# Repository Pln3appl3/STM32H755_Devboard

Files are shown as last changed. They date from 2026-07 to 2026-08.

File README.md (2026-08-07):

# STM32H755_Devboard
A custom devboard using the STM32H755 chip that I built to be used to prototype and test complex robotics machines I plan to build in the future and consists of MicroSD card slot, CAN-FD inbuilt, USB-C, SWD Debug header, boot and reset buttons to flash with USB-C, and external flash.

## Why did I make this?
I made this as I wanted a high-end microcontroller that has a dual core processor and has multiple functionalities, and that eventually led to me making this custom devboard that I plan on using to test prototypes for any complex robots I want to make and not worry about being bottlenecked by the microcontroller.

## Pictures
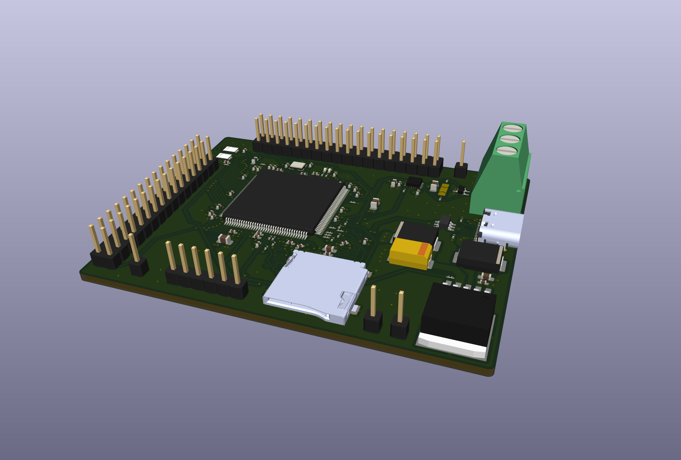
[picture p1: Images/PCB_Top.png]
PCB Top

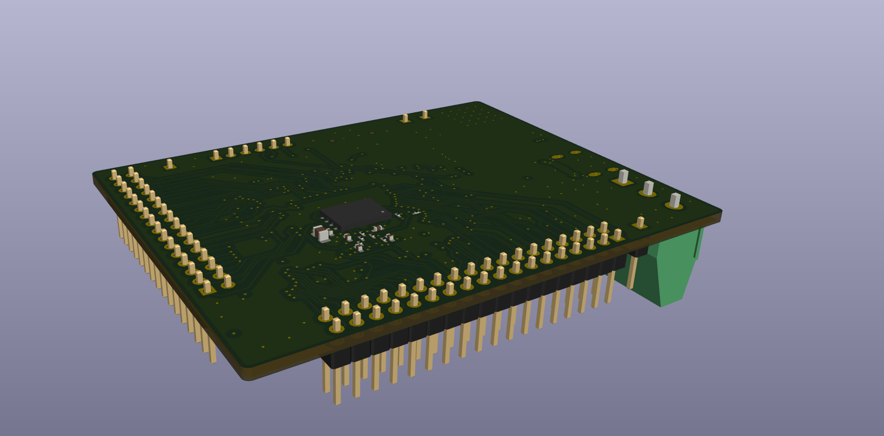
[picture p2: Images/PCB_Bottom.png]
PCB Bottom


## Footprint Pictures
### Top Layer
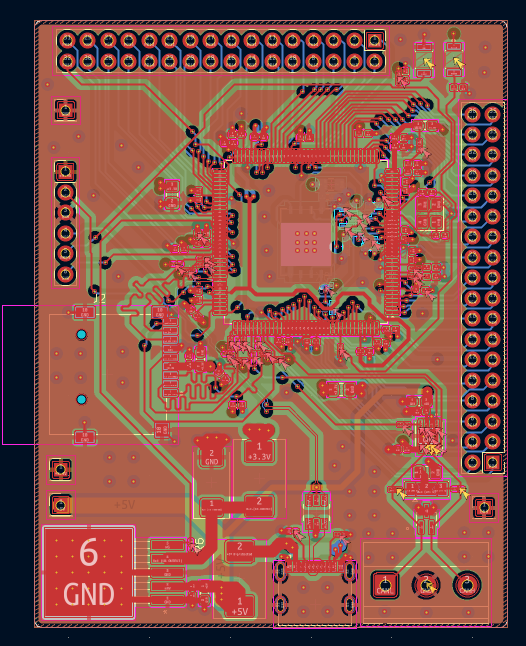
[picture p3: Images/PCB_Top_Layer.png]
PCB Top Layer


### GND Layer
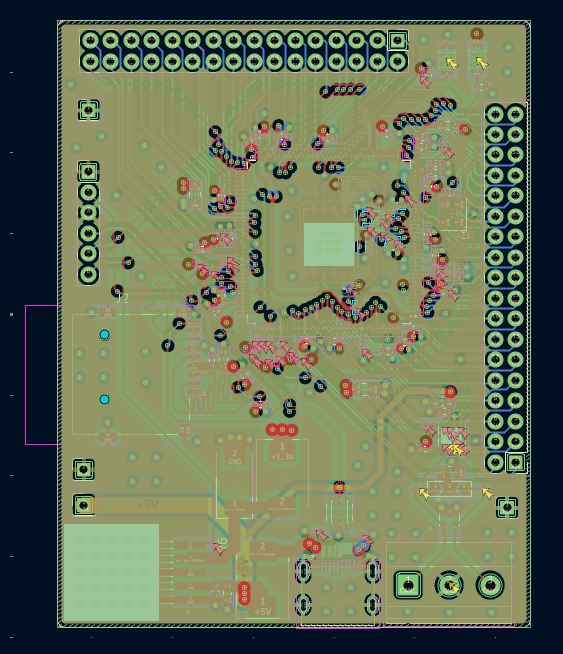
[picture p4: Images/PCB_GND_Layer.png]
PCB GND Layer


### Power Layer
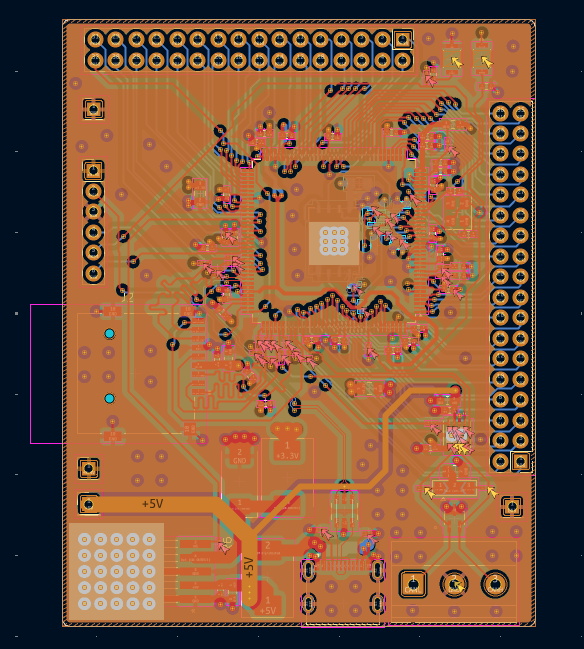
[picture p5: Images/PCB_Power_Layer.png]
PCB Power Layer


### Bottom Layer
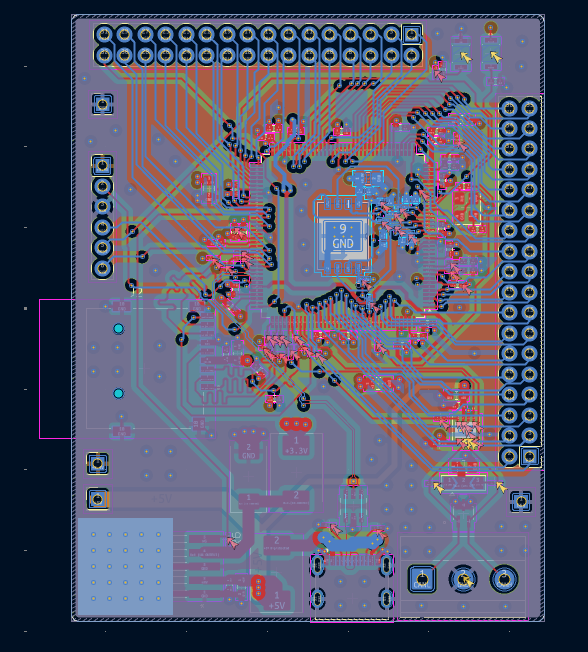
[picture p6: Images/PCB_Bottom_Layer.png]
PCB Bottom Layer


### BOM
| Component | Amount | Price per unit | Total Price | Purpose | Link |
|---|---|---|---|---|---|
| STM32H755ZIT3 | 1 | $20.11 | $20.11 | MCU for the board | https://www.digikey.com/en/products/detail/stmicroelectronics/STM32H755ZIT3/18086228 |
| TYPE-C-16P-3MD | 1 | $0.19 | $1.90 | USB-C data and power (Had to buy 10 as that was the minimum purchase amount | https://www.digikey.com/en/products/detail/shenzhen-shouhan-technology-co-ltd/type-c-16p-3md/29627623 |
| USBLC6-2SC6Y | 1 | $0.67 | $0.67 | ESD protection for data lines | https://www.digikey.com/en/products/detail/stmicroelectronics/usblc6-2sc6y/2819177 |
| SSC54-E3/57T | 2 | $1.05 | $2.10 | Diode to prevent reverse current | https://www.digikey.com/en/products/detail/vishay-general-semiconductor-diodes-division/ssc54-e3-57t/1091564 |
| TPS75733KTTR | 1 | $11.26 | $11.26 | 3.3V LDO | https://www.digikey.com/en/products/detail/texas-instruments/tps75733kttr/1673150 |
| TCAN1044VDRBRQ1 | 1 | $1.86 | $1.86 | CAN-FD Transceiver | https://www.digikey.com/en/products/detail/texas-instruments/tcan1044vdrbrq1/13245687 |
| ESD2CAN24DCKRQ1 | 1 | $0.40 | $0.40 | ESD protection for CAN-FD | https://www.digikey.com/en/products/detail/texas-instruments/esd2can24dckrq1/16982070 |
| TSX-3225_25.0000MF20X-AJ0 | 1 | $0.37 | $0.37 | 25MHz crystal | https://www.digikey.com/en/products/detail/epson/TSX-3225-25-0000MF20X-AJ0/5168442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 |
| W25Q256JVEIQ TR | 1 | $6.08 | $6.08 | External Flash | https://www.digikey.com/en/products/detail/winbond-electronics/w25q256jveiq-tr/5803969 |
| MSD-1-A | 1 | $0.38 | $0.38 | MicroSD card port | https://www.digikey.com/en/products/detail/same-sky-formerly-cui-devices/msd-1-a/21799641 |
| EVP-AWBD4A | 2 | $0.30 | $0.60 | Button for boot and reset | https://www.digikey.com/en/products/detail/panasonic-industry/EVP-AWBD4A/8568273 |
| GRM155Z71A225KE44D | 2 | $0.15 | $0.30 | VCAP Capacitors with under .1 Ohm ESR | https://www.digikey.com/en/products/detail/murata-electronics/GRM155Z71A225KE44D/10264880 |
| C2012X7R1A475K085AC | 4 | $0.27 | $1.08 | Buk and filtering capacitor | https://www.digikey.com/en/products/detail/tdk/C2012X7R1A475K085AC/3951763 |
| GRT188R61C106KE13D | 3 | $0.29 | $0.87 | Bulk Capacitor | https://www.digikey.com/en/products/detail/murata-electronics/GRT188R61C106KE13D/5416739 |
| KAM05CR71A105KH | 4 | $0.17 | $0.68 | Decoupling/Filtering capacitor | https://www.digikey.com/en/products/detail/kyocera-avx/KAM05CR71A105KH/22198421 |
| CC0402JRX7R8BB104 | 31 | $0.05 | $1.58 | Decoupling capacitor | https://www.digikey.com/en/products/detail/yageo/CC0402JRX7R8BB104/11491448 |
| C0402C100F4HACAUTO | 2 | $0.18 | $0.36 | Crystal load capacitor | https://www.digikey.com/en/products/detail/kemet/C0402C100F4HACAUTO/7955039 |
| T495D476K025ATE250 | 1 | $2.36 | $2.36 | LDO output bulk capacitor | https://www.digikey.com/en/products/detail/kemet/T495D476K025ATE250/3760574 |
| BLM18SG121TN1D | 1 | $0.14 | $0.14 | Ferrite bead for analog filtering | https://www.digikey.com/en/products/detail/murata-electronics/blm18sg121tn1d/1016155 |
| RC0201JR-070RL | 1 | $0.10 | $0.10 | Resistor Jumper for VREF+ | https://www.digikey.com/en/products/detail/yageo/RC0201JR-070RL/1948898 |
| RC0201FR-0710KL | 10 | $0.03 | $0.34 | 10K ohm Pull-up resistor | https://www.digikey.com/en/products/detail/yageo/RC0201FR-0710KL/1948870 |
| RC0201FR-0733RL | 2 | $0.10 | $0.20 | 33 Ohm dampening resistor | https://www.digikey.com/en/products/detail/yageo/RC0201FR-0733RL/1948893 |
| RC0201FR-0722RL | 12 | $0.03 | $0.41 | 22 Ohm dampening resistor | https://www.digikey.com/en/products/detail/yageo/RC0201FR-0722RL/5280378 |
| RC0201FR-07330RL | 2 | $0.10 | $0.20 | 330 Ohm current limiting resistor | https://www.digikey.com/en/products/detail/yageo/RC0201FR-07330RL/5280464 |
| RC0201FR-135K1L | 2 | $0.10 | $0.20 | USB-C detection pull-down resistor | https://www.digikey.com/en/products/detail/yageo/RC0201FR-135K1L/17017100 |
| RC0201FR-0760R4L | 2 | $0.10 | $0.20 | CAN-FD Termination resistors | https://www.digikey.com/en/products/detail/yageo/RC0201FR-0760R4L/5280609 |
| XZMDK68W-2 | 1 | $0.23 | $0.23 | Debug LED | https://www.digikey.com/en/products/detail/sunled/XZMDK68W-2/4745956 |
| XZVG68W-2 | 1 | $0.26 | $0.26 | Debug LED | https://www.digikey.com/en/products/detail/sunled/XZVG68W-2/4745975 |
| M50-3530242 | 39 | $0.08 | $3.28 | Headers | https://www.digikey.com/en/products/detail/harwin-inc/M50-3530242/7044013 |
| 1729131 | 1 | $1.44 | $1.44 | CAN-FD Terminal Block | https://www.digikey.com/en/products/detail/phoenix-contact/1729131/260616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 |
|PCB |5 | $15.32 | $76.60 | ||
| Total | | | $130.36 | | |

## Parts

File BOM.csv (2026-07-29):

Name | Price
PCB | $53.76
Parts | $76.60
Total | $130.36

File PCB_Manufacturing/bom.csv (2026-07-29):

Component | Amount | Price per unit | Total Price | Link
STM32H755ZIT3 | 1 | $20.11 | $20.11 | https://www.digikey.com/en/products/detail/stmicroelectronics/STM32H755ZIT3/18086228
TYPE-C-16P-3MD | 1 | $0.19 | $1.90 | https://www.digikey.com/en/products/detail/shenzhen-shouhan-technology-co-ltd/type-c-16p-3md/29627623
USBLC6-2SC6Y | 1 | $0.67 | $0.67 | https://www.digikey.com/en/products/detail/stmicroelectronics/usblc6-2sc6y/2819177
SSC54-E3/57T | 2 | $1.05 | $2.10 | https://www.digikey.com/en/products/detail/vishay-general-semiconductor-diodes-division/ssc54-e3-57t/1091564
TPS75733KTTR | 1 | $11.26 | $11.26 | https://www.digikey.com/en/products/detail/texas-instruments/tps75733kttr/1673150
TCAN1044VDRBRQ1 | 1 | $1.86 | $1.86 | https://www.digikey.com/en/products/detail/texas-instruments/tcan1044vdrbrq1/13245687
ESD2CAN24DCKRQ1 | 1 | $0.40 | $0.40 | https://www.digikey.com/en/products/detail/texas-instruments/esd2can24dckrq1/16982070
TSX-3225_25.0000MF20X-AJ0 | 1 | $0.37 | $0.37 | https://www.digikey.com/en/products/detail/epson/TSX-3225-25-0000MF20X-AJ0/5168442
W25Q256JVEIQ TR | 1 | $6.08 | $6.08 | https://www.digikey.com/en/products/detail/winbond-electronics/w25q256jveiq-tr/5803969
MSD-1-A | 1 | $0.38 | $0.38 | https://www.digikey.com/en/products/detail/same-sky-formerly-cui-devices/msd-1-a/21799641
EVP-AWBD4A | 2 | $0.30 | $0.60 | https://www.digikey.com/en/products/detail/panasonic-industry/EVP-AWBD4A/8568273
GRM155Z71A225KE44D | 2 | $0.15 | $0.30 | https://www.digikey.com/en/products/detail/murata-electronics/GRM155Z71A225KE44D/10264880
C2012X7R1A475K085AC | 4 | $0.27 | $1.08 | https://www.digikey.com/en/products/detail/tdk/C2012X7R1A475K085AC/3951763
GRT188R61C106KE13D | 3 | $0.29 | $0.87 | https://www.digikey.com/en/products/detail/murata-electronics/GRT188R61C106KE13D/5416739
KAM05CR71A105KH | 4 | $0.17 | $0.68 | https://www.digikey.com/en/products/detail/kyocera-avx/KAM05CR71A105KH/22198421
CC0402JRX7R8BB104 | 31 | $0.05 | $1.58 | https://www.digikey.com/en/products/detail/yageo/CC0402JRX7R8BB104/11491448
C0402C100F4HACAUTO | 2 | $0.18 | $0.36 | https://www.digikey.com/en/products/detail/kemet/C0402C100F4HACAUTO/7955039
T495D476K025ATE250 | 1 | $2.36 | $2.36 | https://www.digikey.com/en/products/detail/kemet/T495D476K025ATE250/3760574
BLM18SG121TN1D | 1 | $0.14 | $0.14 | https://www.digikey.com/en/products/detail/murata-electronics/blm18sg121tn1d/1016155
RC0201JR-070RL | 1 | $0.10 | $0.10 | https://www.digikey.com/en/products/detail/yageo/RC0201JR-070RL/1948898
RC0201FR-0710KL | 10 | $0.03 | $0.34 | https://www.digikey.com/en/products/detail/yageo/RC0201FR-0710KL/1948870
RC0201FR-0733RL | 2 | $0.10 | $0.20 | https://www.digikey.com/en/products/detail/yageo/RC0201FR-0733RL/1948893
RC0201FR-0722RL | 12 | $0.03 | $0.41 | https://www.digikey.com/en/products/detail/yageo/RC0201FR-0722RL/5280378
RC0201FR-07330RL | 2 | $0.10 | $0.20 | https://www.digikey.com/en/products/detail/yageo/RC0201FR-07330RL/5280464
RC0201FR-135K1L | 2 | $0.10 | $0.20 | https://www.digikey.com/en/products/detail/yageo/RC0201FR-135K1L/17017100
RC0201FR-0760R4L | 2 | $0.10 | $0.20 | https://www.digikey.com/en/products/detail/yageo/RC0201FR-0760R4L/5280609
XZMDK68W-2 | 1 | $0.23 | $0.23 | https://www.digikey.com/en/products/detail/sunled/XZMDK68W-2/4745956
XZVG68W-2 | 1 | $0.26 | $0.26 | https://www.digikey.com/en/products/detail/sunled/XZVG68W-2/4745975
M50-3530242 | 39 | $0.08 | $3.28 | https://www.digikey.com/en/products/detail/harwin-inc/M50-3530242/7044013
1729131 | 1 | $1.44 | $1.44 | https://www.digikey.com/en/products/detail/phoenix-contact/1729131/260616?gclsrc=aw.ds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
Total |  |  | $58.97

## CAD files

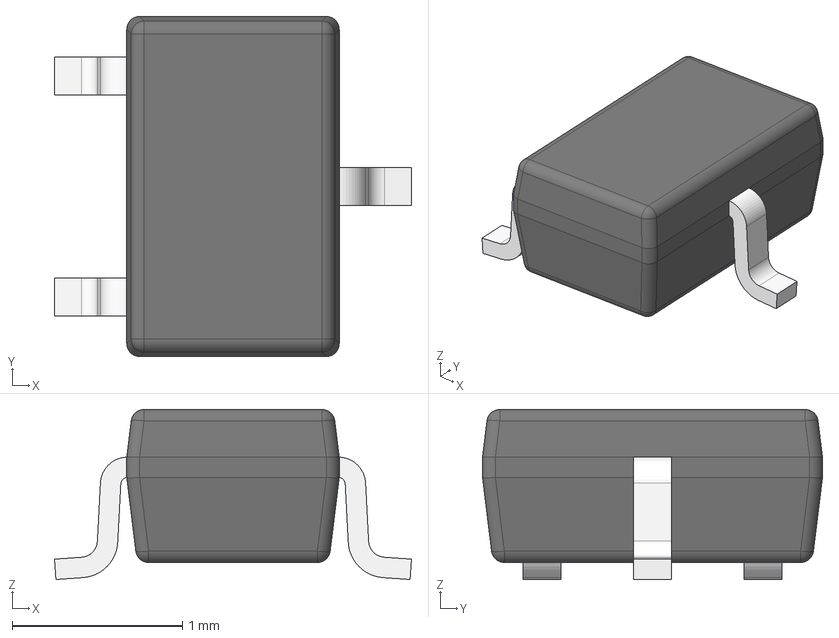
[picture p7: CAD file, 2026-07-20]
KiCad_Models/ESD2CAN24DCKRQ1/DCK0003A.stp
2.10 x 2.00 x 1.00 mm
BODY-SOT
LEAD-SOT x 3
PIN1-ID

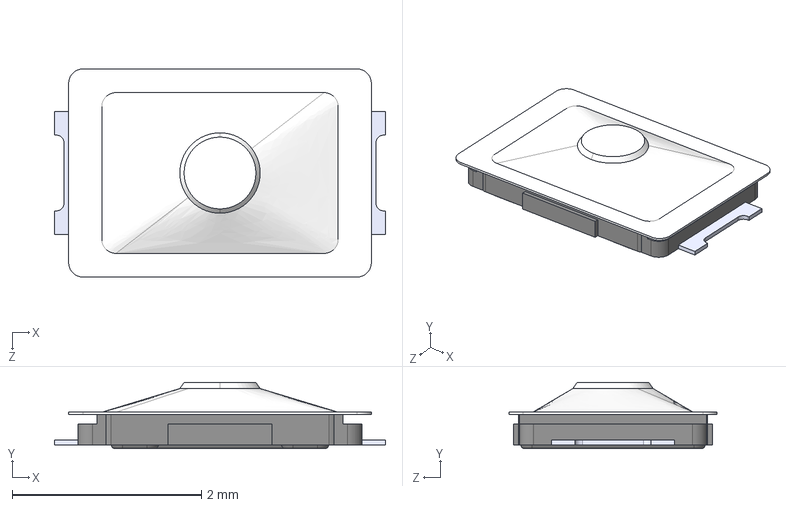
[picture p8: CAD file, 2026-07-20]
KiCad_Models/EVP-AWBD4A/EVP-AWBD4A.step
3.50 x 0.7 x 2.20 mm

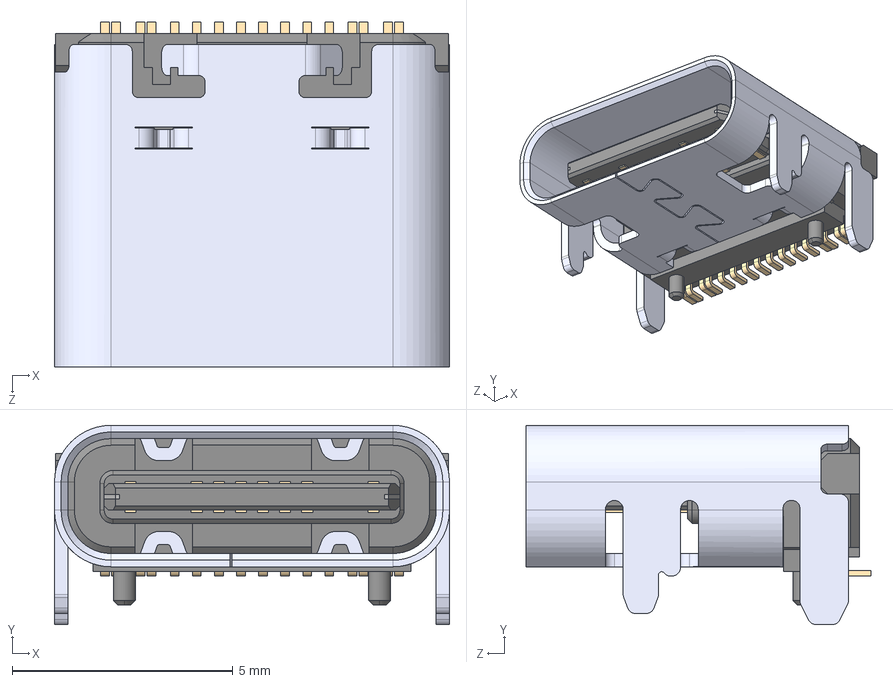
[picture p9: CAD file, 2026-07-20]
KiCad_Models/KH-TYPE-C-16P/KH-TYPE-C-16P.step
8.94 x 4.51 x 7.81 mm

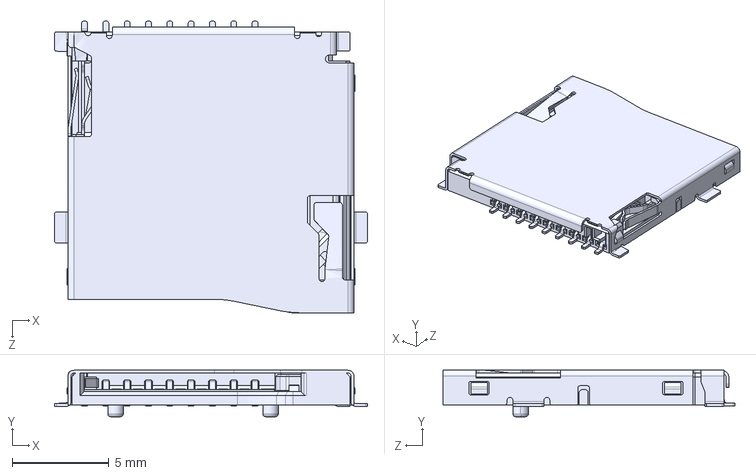
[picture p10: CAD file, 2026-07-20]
KiCad_Models/MSD_1_A/MSD-1-A.step
16.1 x 2.40 x 15.0 mm

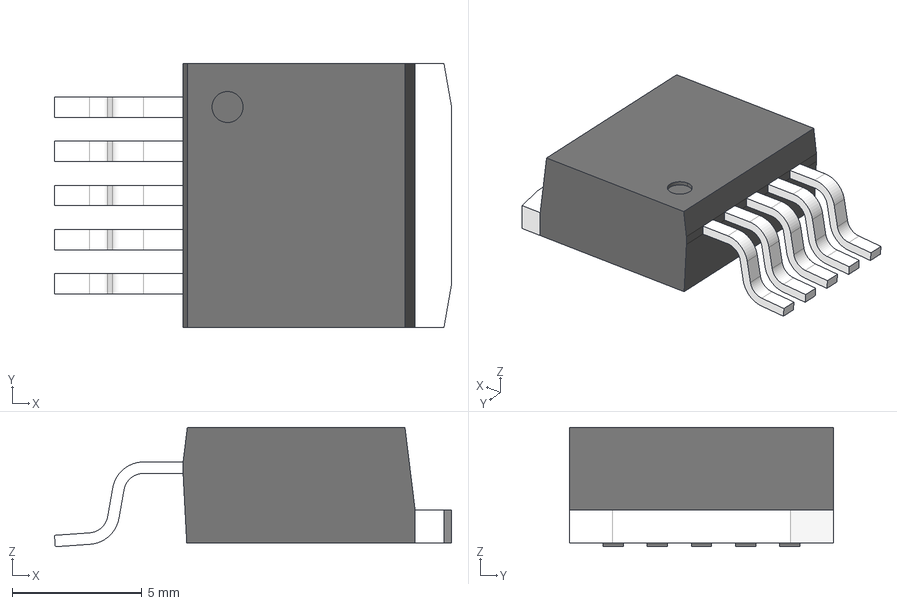
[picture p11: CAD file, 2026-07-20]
KiCad_Models/TPS75733KTTR/KTT0005A.stp
15.3 x 10.2 x 4.60 mm
HTSINK
LEAD x 5

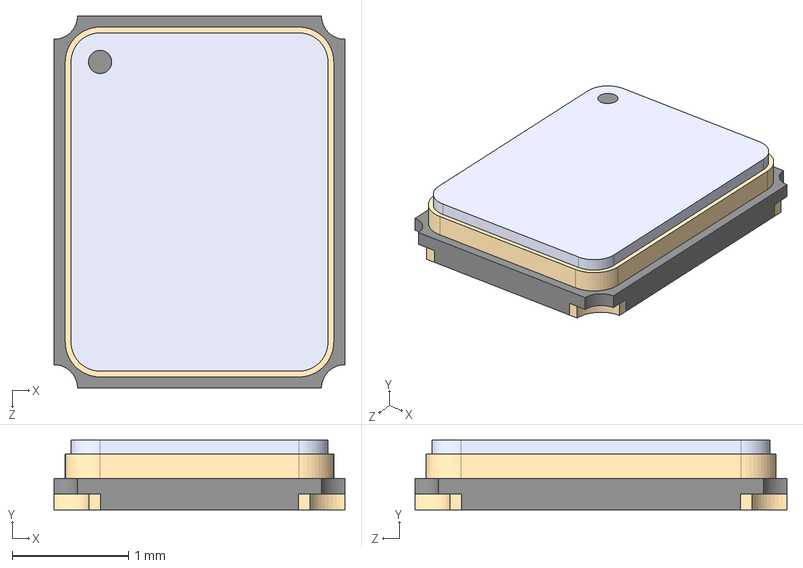
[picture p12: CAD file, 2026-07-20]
KiCad_Models/TSX_3225_25_0000MF20X_AJ0/TSX-3225_25.0000MF20X-AJ0.step
2.50 x 0.6 x 3.20 mm

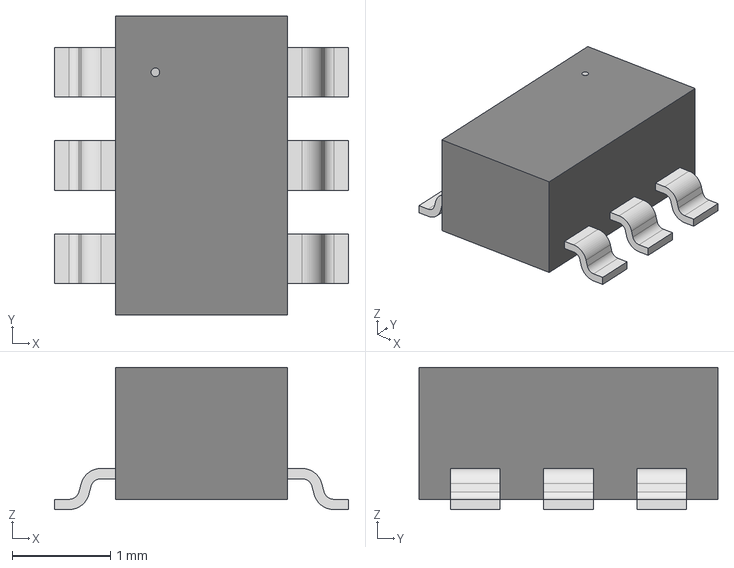
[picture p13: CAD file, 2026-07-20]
KiCad_Models/USBLC6-2SC6Y/SOT23-6L_STM.step
3.00 x 3.05 x 1.45 mm

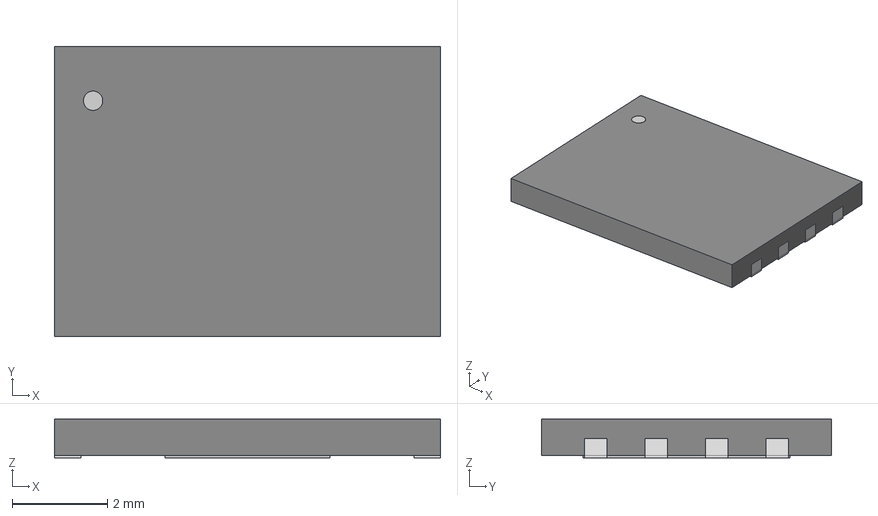
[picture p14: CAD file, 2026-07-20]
KiCad_Models/W25Q256JVEIQ/WSON8_E_WIN.step
8.10 x 6.10 x 0.815 mm

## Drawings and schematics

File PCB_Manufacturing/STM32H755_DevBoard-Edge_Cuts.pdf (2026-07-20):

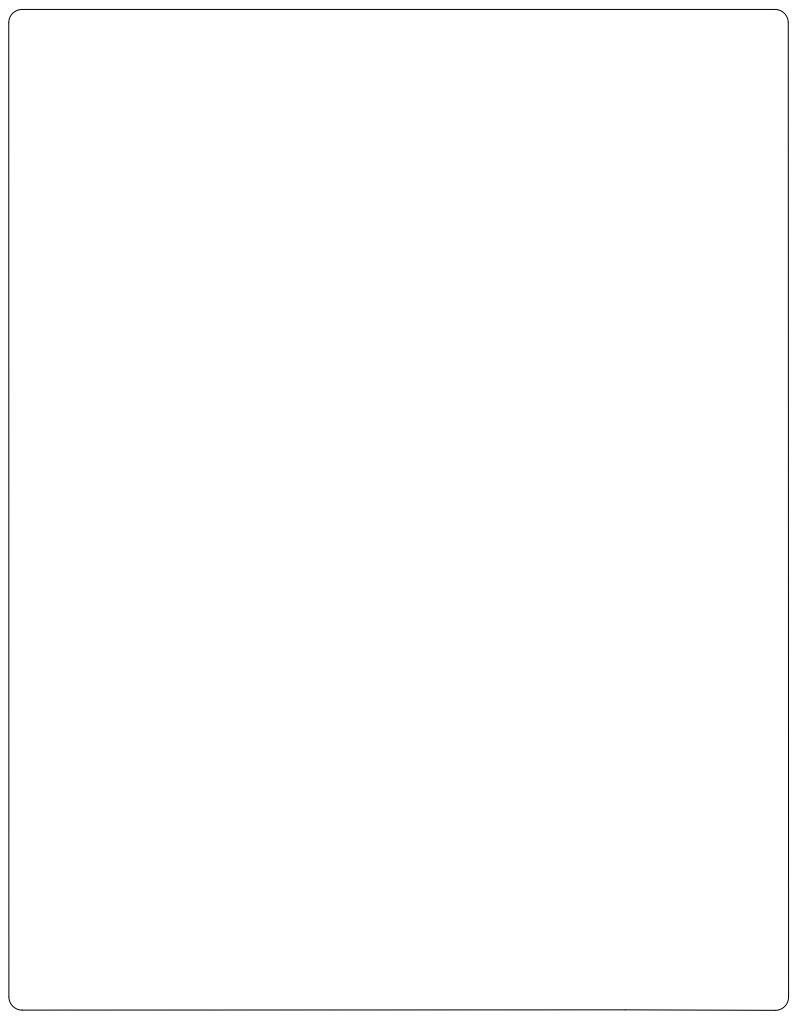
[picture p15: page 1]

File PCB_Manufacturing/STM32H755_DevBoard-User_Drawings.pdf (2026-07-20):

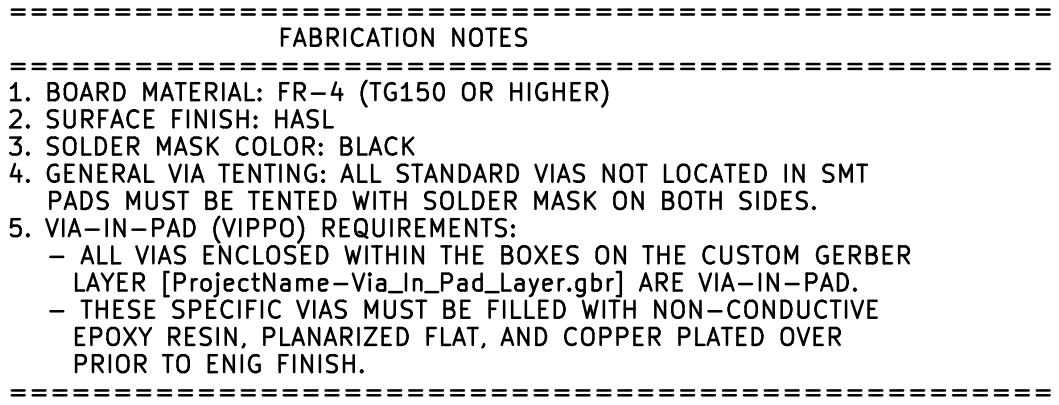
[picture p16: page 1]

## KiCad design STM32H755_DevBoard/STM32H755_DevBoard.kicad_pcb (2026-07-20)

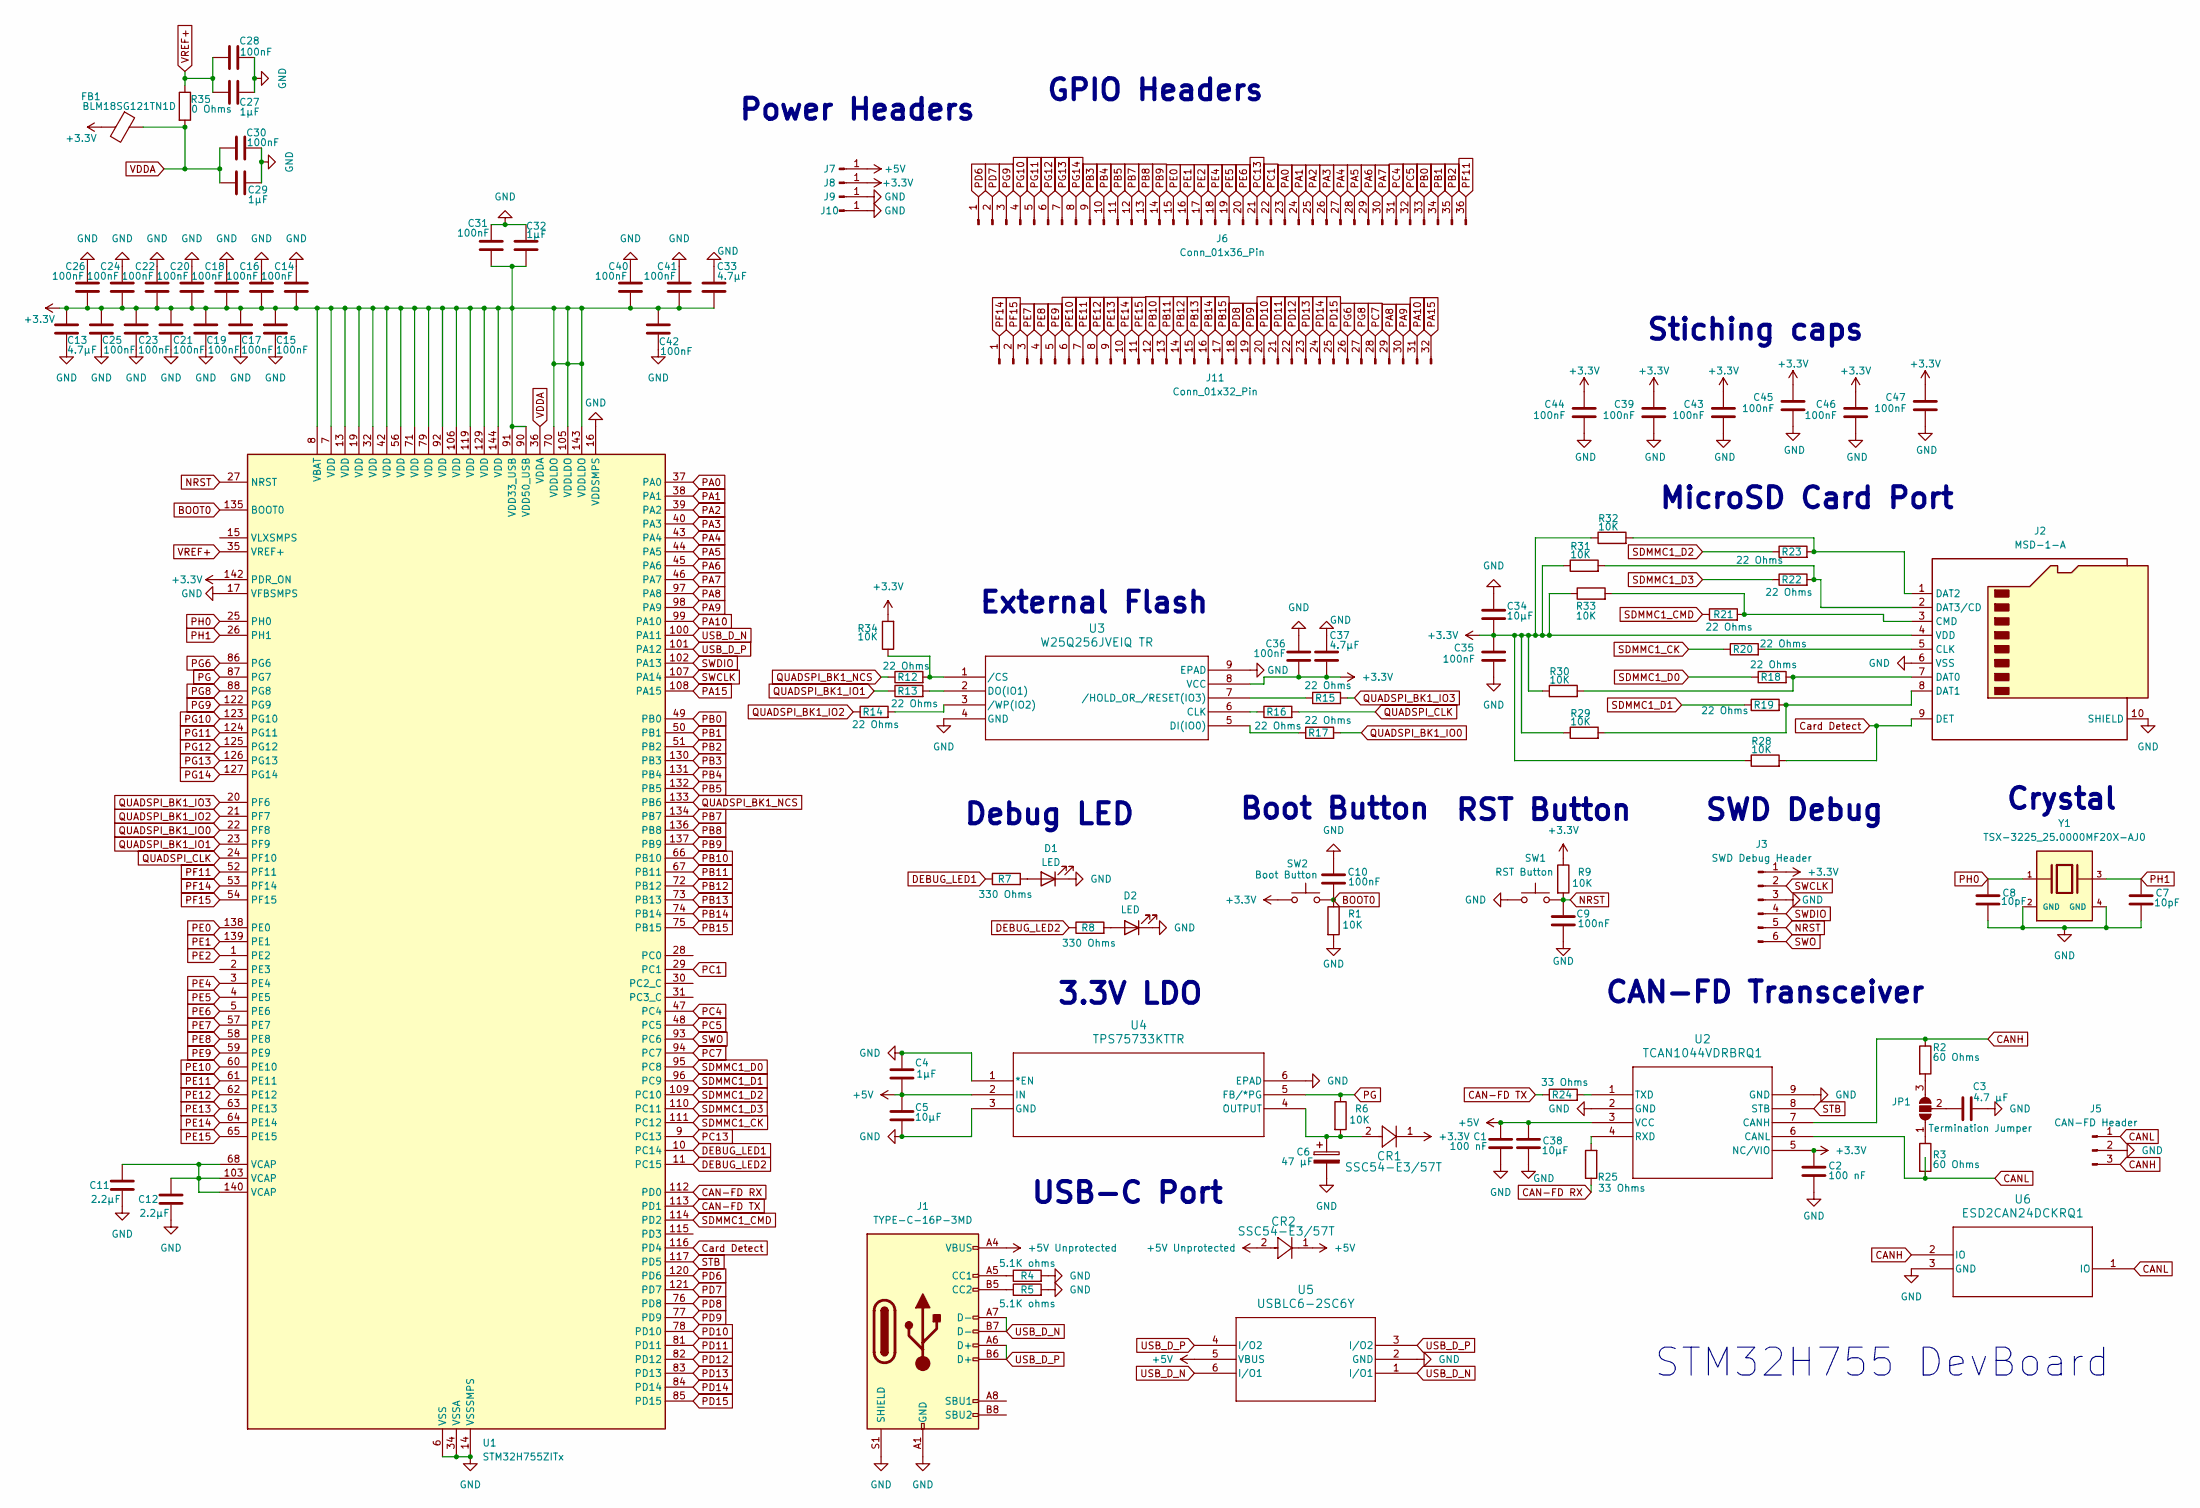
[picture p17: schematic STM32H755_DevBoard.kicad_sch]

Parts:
C1, C2: 100 nF; C_0402_1005Metric_Pad0.74x0.62mm_HandSolder
C3: 4.7 μF; C_0805_2012Metric_Pad1.18x1.45mm_HandSolder
C4, C27, C29, C32: 1µF; C_0402_1005Metric_Pad0.74x0.62mm_HandSolder
C5, C34, C38: 10µF; C_0603_1608Metric_Pad1.08x0.95mm_HandSolder
C6: 47 μF; CP_EIA-7343-31_Kemet-D
C7, C8: 10pF; C_0402_1005Metric_Pad0.74x0.62mm_HandSolder
C9, C10, C14, C15, C16, C17, C18, C19, C20, C21, C22, C23, C24, C25, C26, C28, C30, C31, C35, C36, C39, C40, C41, C42, C43, C44, C45, C46, C47: 100nF; C_0402_1005Metric_Pad0.74x0.62mm_HandSolder
C11, C12: 2.2µF; C_0402_1005Metric_Pad0.74x0.62mm_HandSolder
C13, C33, C37: 4.7µF; C_0805_2012Metric_Pad1.18x1.45mm_HandSolder
CR1, CR2: SSC54-E3/57T; D_SMC
D1, D2: LED; LED_0402_1005Metric_Pad0.77x0.64mm_HandSolder
FB1: BLM18SG121TN1D; L_0603_1608Metric_Pad1.05x0.95mm_HandSolder
J1: TYPE-C-16P-3MD; KINGHELM_KH-TYPE-C-16P
J2: MSD-1-A; CUI_MSD-1-A
J3: SWD Debug Header; PinHeader_1x06_P2.54mm_Vertical
J5: CAN-FD Header; TerminalBlock_Phoenix_MKDS-1,5-3-5.08_1x03_P5.08mm_Horizont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
J6: Conn_01x36_Pin; PinHeader_2x18_P2.54mm_Vertical
J7, J8, J9, J10: Conn_01x01_Pin; PinHeader_1x01_P2.54mm_Vertical
J11: Conn_01x32_Pin; PinHeader_2x16_P2.54mm_Vertical
JP1: Termination Jumper; SolderJumper-3_P2.0mm_Open_TrianglePad1.0x1.5mm
R1, R6, R9, R28, R29, R30, R31, R32, R33, R34: 10K; R_0201_0603Metric_Pad0.64x0.40mm_HandSolder
R2, R3: 60 Ohms; R_0201_0603Metric_Pad0.64x0.40mm_HandSolder
R4, R5: 5.1K ohms; R_0201_0603Metric_Pad0.64x0.40mm_HandSolder
R7, R8: 330 Ohms; R_0201_0603Metric_Pad0.64x0.40mm_HandSolder
R12, R13, R14, R15, R16, R17, R18, R19, R20, R21, R22, R23: 22 Ohms; R_0201_0603Metric_Pad0.64x0.40mm_HandSolder
R24, R25: 33 Ohms; R_0201_0603Metric_Pad0.64x0.40mm_HandSolder
R35: 0 Ohms; R_0201_0603Metric_Pad0.64x0.40mm_HandSolder
SW1: RST Button; SW_EVP-AWBD4A
SW2: Boot Button; SW_EVP-AWBD4A
U1: STM32H755ZITx; LQFP-144_20x20mm_P0.5mm
U2: TCAN1044VDRBRQ1; SON8_DRB_TEX-M
U3: W25Q256JVEIQ TR; WSON8_E_WIN-M
U4: TPS75733KTTR; KTT5_6P22X6P86-M
U5: USBLC6-2SC6Y; SOT23-6L_STM-M
U6: ESD2CAN24DCKRQ1; SOT-SC70_3_DCK_TEX-M
Y1: TSX-3225_25.0000MF20X-AJ0; Crystal_SMD_3225-4Pin_3.2x2.5mm; PARTREV N/A

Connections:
+3.3V: C2.1, C13.1, C14.1, C15.1, C16.1, C17.1, C18.1, C19.1, C20.1, C21.1, C22.1, C23.1, C24.1, C25.1, C26.1, C31.1, C32.1, C33.1, C34.2, C35.1, C36.1, C37.1, C39.1, C40.1, C41.1, C42.1, C43.1, C44.1, C45.1, C46.1, C47.1, CR1.1, FB1.2, J2.4 (VDD), J3.1, J8.1, R9.1, R28.1, R29.1, R30.1, R31.1, R32.1, R33.1, R34.2, SW2.1, U1.7 (VDD), U1.8 (VBAT), U1.13 (VDD), U1.19 (VDD), U1.32 (VDD), U1.42 (VDD), U1.56 (VDD), U1.70 (VDDLDO), U1.71 (VDD), U1.79 (VDD), U1.90 (VDD50_USB), U1.91 (VDD33_USB), U1.92 (VDD), U1.105 (VDDLDO), U1.106 (VDD), U1.119 (VDD), U1.129 (VDD), U1.142 (PDR_ON), U1.143 (VDDLDO), U1.144 (VDD), U2.5 (NC/VIO), U3.8 (VCC)
+5V: C1.1, C4.2, C5.1, C38.2, CR2.1, J7.1, U2.3 (VCC), U4.2 (IN), U5.5 (VBUS)
+5V Unprotected: CR2.2, J1.A4 (VBUS), J1.B9 (VBUS)
BOOT0: C10.1, R1.1, SW2.2, U1.135 (BOOT0)
CAN-FD RX: R25.1, U1.112 (PD0)
CAN-FD TX: R24.1, U1.113 (PD1)
CANH: J5.3, R2.1, U2.7 (CANH), U6.2 (IO)
CANL: J5.1, R3.2, U2.6 (CANL), U6.1 (IO)
Card Detect: J2.9 (DET), R28.2, U1.116 (PD4)
DEBUG_LED1: R7.1, U1.10 (PC14)
DEBUG_LED2: R8.1, U1.11 (PC15)
GND: C1.2, C2.2, C3.2, C4.1, C5.2, C6.2, C7.2, C8.2, C9.2, C10.2, C11.2, C12.2, C13.2, C14.2, C15.2, C16.2, C17.2, C18.2, C19.2, C20.2, C21.2, C22.2, C23.2, C24.2, C25.2, C26.2, C27.2, C28.2, C29.2, C30.2, C31.2, C32.2, C33.2, C34.1, C35.2, C36.2, C37.2, C38.1, C39.2, C40.2, C41.2, C42.2, C43.2, C44.2, C45.2, C46.2, C47.2, D1.1 (K), D2.1 (K), J1.A1 (GND), J1.A12 (GND), J1.S1 (SHIELD), J2.6 (VSS), J2.10 (SHIELD), J3.3, J5.2, J9.1, J10.1, R1.2, R4.2, R5.2, SW1.1, U1.6 (VSS), U1.12 (VSS), U1.14 (VSSSMPS), U1.16 (VDDSMPS), U1.17 (VFBSMPS), U1.18 (VSS), U1.33 (VSS), U1.34 (VSSA), U1.41 (VSS), U1.55 (VSS), U1.69 (VSS), U1.80 (VSS), U1.89 (VSS), U1.104 (VSS), U1.118 (VSS), U1.128 (VSS), U1.141 (VSS), U2.2 (GND), U2.9 (GND), U3.4 (GND), U3.9 (EPAD), U4.1 (*EN), U4.3 (GND), U4.6 (EPAD), U5.2 (GND), U6.3 (GND), Y1.2 (GND), Y1.4 (GND)
NRST: C9.1, J3.5, R9.2, SW1.2, U1.27 (NRST)
unnamed: C11.1, C12.1, U1.68 (VCAP), U1.103 (VCAP), U1.140 (VCAP)
unnamed: D1.2 (A), R7.2
unnamed: D2.2 (A), R8.2
unnamed: J1.A5 (CC1), R4.1
unnamed: J1.B5 (CC2), R5.1
unnamed: J2.5 (CLK), R20.2
unnamed: J2.3 (CMD), R21.2, R33.2
unnamed: J2.7 (DAT0), R18.2, R30.2
unnamed: J2.8 (DAT1), R19.2, R29.2
unnamed: J2.1 (DAT2), R23.2, R32.2
unnamed: J2.2 (DAT3/CD), R22.2, R31.2
unnamed: JP1.1 (A), R3.1
unnamed: JP1.3 (B), R2.2
unnamed: C3.1, JP1.2 (C)
unnamed: R25.2, U2.4 (RXD)
unnamed: R24.2, U2.1 (TXD)
unnamed: R16.1, U3.6 (CLK)
unnamed: R17.1, U3.5 (DI(IO0))
unnamed: R13.2, U3.2 (DO(IO1))
unnamed: R12.2, R34.1, U3.1 (/CS)
unnamed: R15.1, U3.7 (/HOLD_OR_/RESET(IO3))
unnamed: R14.2, U3.3 (/WP(IO2))
unnamed: C6.1, CR1.2, R6.2, U4.4 (OUTPUT)
PA0: J6.23, U1.37 (PA0)
PA1: J6.24, U1.38 (PA1)
PA2: J6.25, U1.39 (PA2)
PA3: J6.26, U1.40 (PA3)
PA4: J6.27, U1.43 (PA4)
PA5: J6.28, U1.44 (PA5)
PA6: J6.29, U1.45 (PA6)
PA7: J6.30, U1.46 (PA7)
PA8: J11.29, U1.97 (PA8)
PA9: J11.30, U1.98 (PA9)
PA10: J11.31, U1.99 (PA10)
PA15: J11.32, U1.108 (PA15)
PB0: J6.33, U1.49 (PB0)
PB1: J6.34, U1.50 (PB1)
PB2: J6.35, U1.51 (PB2)
PB3: J6.9, U1.130 (PB3)
PB4: J6.10, U1.131 (PB4)
PB5: J6.11, U1.132 (PB5)
PB7: J6.12, U1.134 (PB7)
PB8: J6.13, U1.136 (PB8)
PB9: J6.14, U1.137 (PB9)
PB10: J11.12, U1.66 (PB10)
PB11: J11.13, U1.67 (PB11)
PB12: J11.14, U1.72 (PB12)
PB13: J11.15, U1.73 (PB13)
PB14: J11.16, U1.74 (PB14)
PB15: J11.17, U1.75 (PB15)
PC1: J6.22, U1.29 (PC1)
PC4: J6.31, U1.47 (PC4)
PC5: J6.32, U1.48 (PC5)
PC7: J11.28, U1.94 (PC7)
PC13: J6.21, U1.9 (PC13)
PD6: J6.1, U1.120 (PD6)
PD7: J6.2, U1.121 (PD7)
PD8: J11.18, U1.76 (PD8)
PD9: J11.19, U1.77 (PD9)
PD10: J11.20, U1.78 (PD10)
PD11: J11.21, U1.81 (PD11)
PD12: J11.22, U1.82 (PD12)
PD13: J11.23, U1.83 (PD13)
PD14: J11.24, U1.84 (PD14)
PD15: J11.25, U1.85 (PD15)
PE0: J6.15, U1.138 (PE0)
PE1: J6.16, U1.139 (PE1)
PE2: J6.17, U1.1 (PE2)
PE4: J6.18, U1.3 (PE4)
PE5: J6.19, U1.4 (PE5)
PE6: J6.20, U1.5 (PE6)
PE7: J11.3, U1.57 (PE7)
PE8: J11.4, U1.58 (PE8)
PE9: J11.5, U1.59 (PE9)
PE10: J11.6, U1.60 (PE10)
PE11: J11.7, U1.61 (PE11)
PE12: J11.8, U1.62 (PE12)
PE13: J11.9, U1.63 (PE13)
PE14: J11.10, U1.64 (PE14)
PE15: J11.11, U1.65 (PE15)
PF11: J6.36, U1.52 (PF11)
PF14: J11.1, U1.53 (PF14)
PF15: J11.2, U1.54 (PF15)
PG: R6.1, U1.87 (PG7), U4.5 (FB/*PG)
PG6: J11.26, U1.86 (PG6)
PG8: J11.27, U1.88 (PG8)
PG9: J6.3, U1.122 (PG9)
PG10: J6.4, U1.123 (PG10)
PG11: J6.5, U1.124 (PG11)
PG12: J6.6, U1.125 (PG12)
PG13: J6.7, U1.126 (PG13)
PG14: J6.8, U1.127 (PG14)
PH0: C8.1, U1.25 (PH0), Y1.1
PH1: C7.1, U1.26 (PH1), Y1.3
QUADSPI_BK1_IO0: R17.2, U1.22 (PF8)
QUADSPI_BK1_IO1: R13.1, U1.23 (PF9)
QUADSPI_BK1_IO2: R14.1, U1.21 (PF7)
QUADSPI_BK1_IO3: R15.2, U1.20 (PF6)
QUADSPI_BK1_NCS: R12.1, U1.133 (PB6)
QUADSPI_CLK: R16.2, U1.24 (PF10)
SDMMC1_CK: R20.1, U1.111 (PC12)
SDMMC1_CMD: R21.1, U1.114 (PD2)
SDMMC1_D0: R18.1, U1.95 (PC8)
SDMMC1_D1: R19.1, U1.96 (PC9)
SDMMC1_D2: R23.1, U1.109 (PC10)
SDMMC1_D3: R22.1, U1.110 (PC11)
STB: U1.117 (PD5), U2.8 (STB)
SWCLK: J3.2, U1.107 (PA14)
SWDIO: J3.4, U1.102 (PA13)
SWO: J3.6, U1.93 (PC6)
USB_D_N: J1.A7 (D-), J1.B7 (D-), U1.100 (PA11), U5.1 (I/O1), U5.6 (I/O1)
USB_D_P: J1.A6 (D+), J1.B6 (D+), U1.101 (PA12), U5.3 (I/O2), U5.4 (I/O2)
VDDA: C29.1, C30.1, FB1.1, R35.2, U1.36 (VDDA)
VREF+: C27.1, C28.1, R35.1, U1.35 (VREF+)

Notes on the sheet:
3.3V LDO
RST Button
Stiching caps
GPIO Headers
Power Headers
Crystal
SWD Debug
CAN-FD Transceiver
USB-C Port
External Flash
MicroSD Card Port
STM32H755 DevBoard
Boot Button
Debug LED

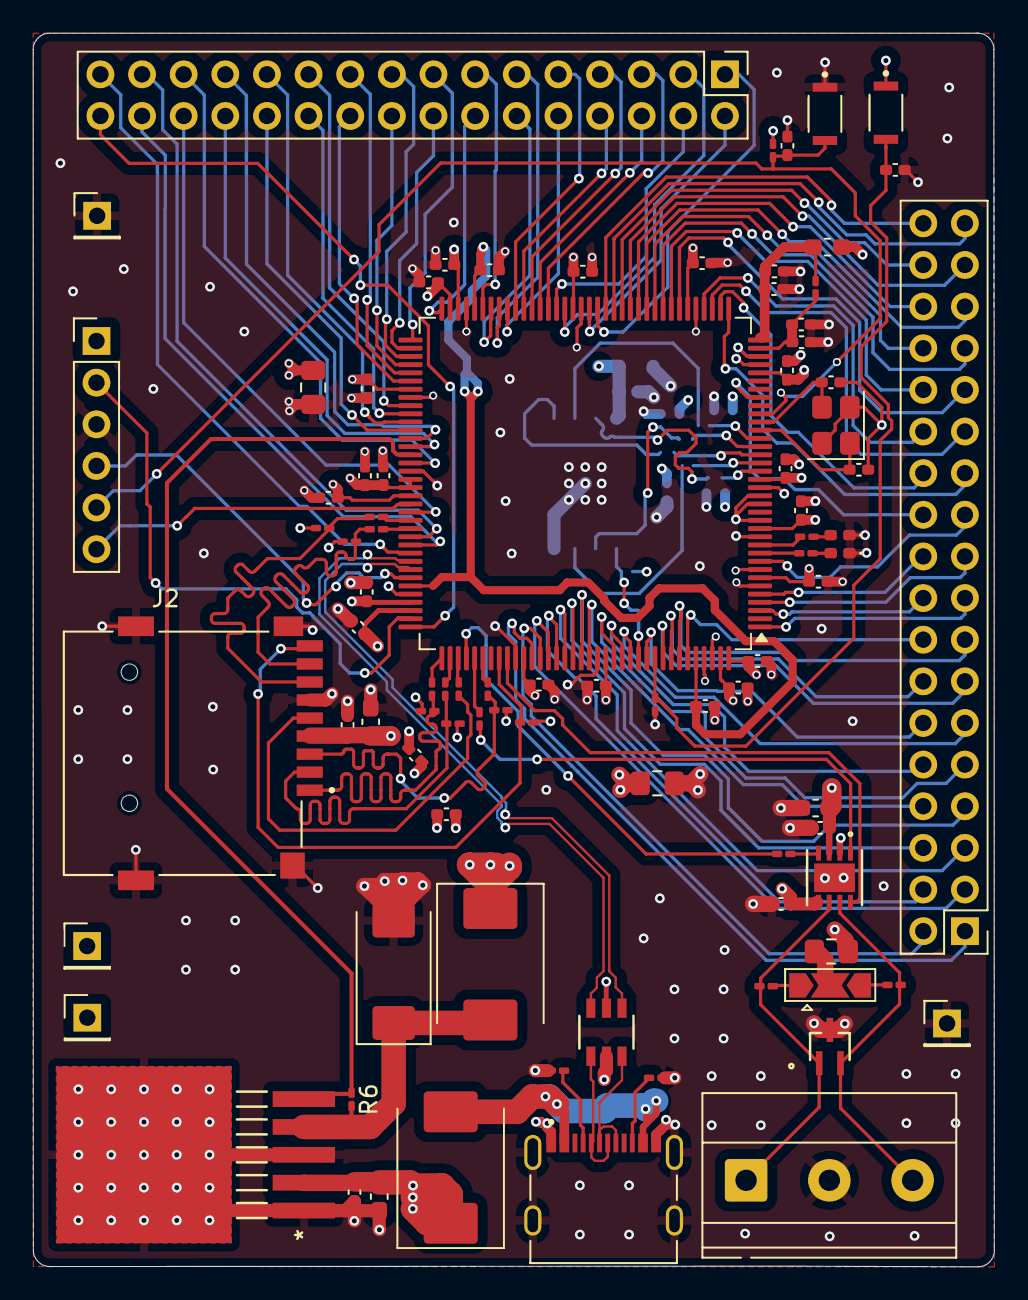
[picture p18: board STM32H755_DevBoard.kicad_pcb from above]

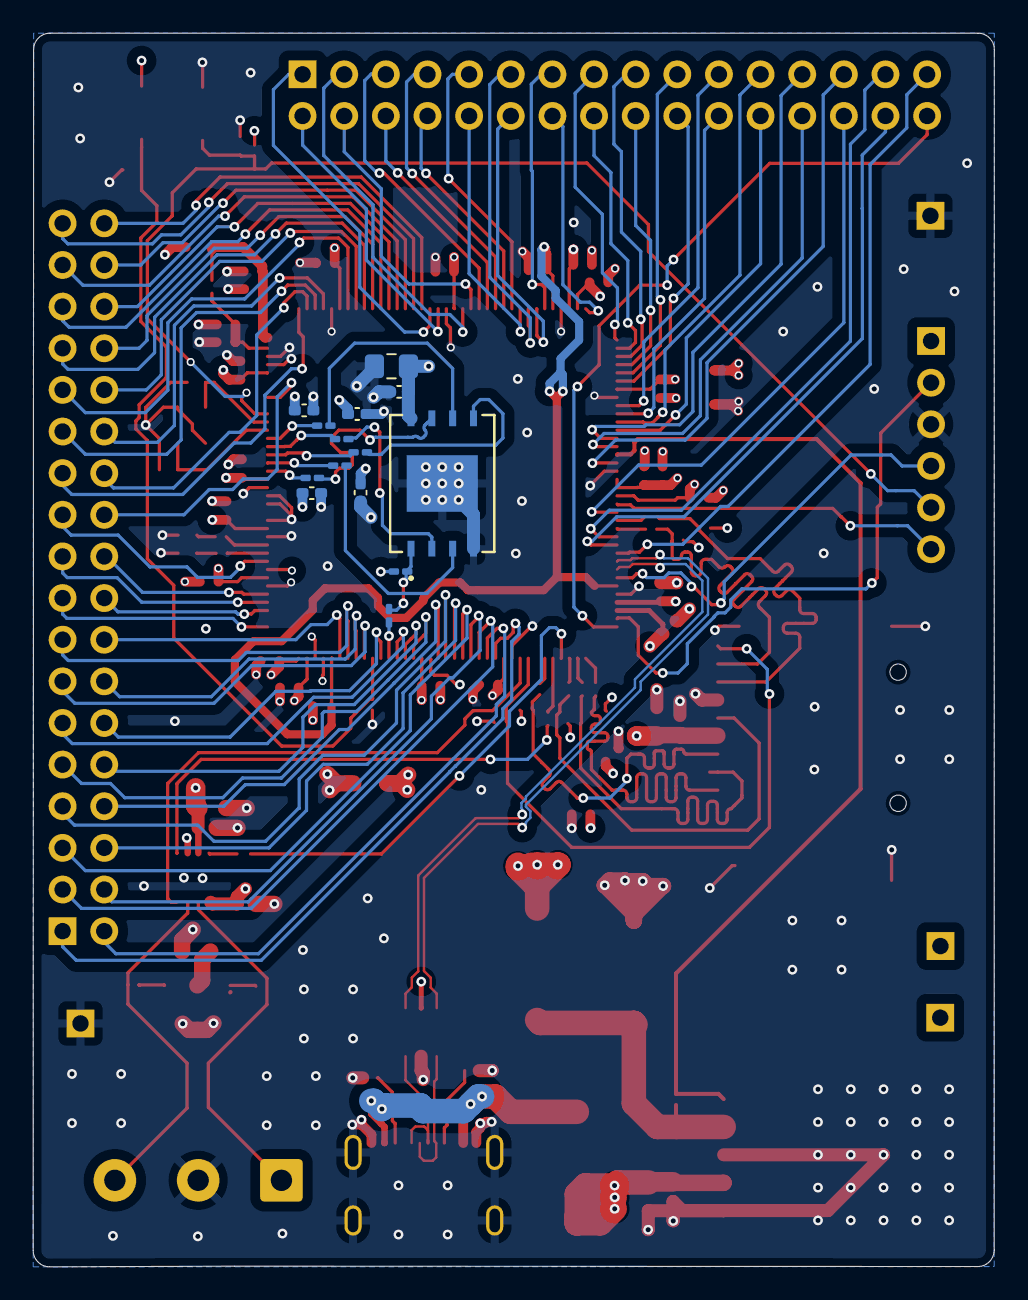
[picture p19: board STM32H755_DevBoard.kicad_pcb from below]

Board: 4 copper layers, 58.6 x 75.3 mm, 103 parts (14 on the bottom side), 127 nets.

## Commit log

2026-07-20 Add files via upload
    Kicad files I had to download since I couldn't find them on Kicad
    [DCK0003A.stp, DRB0008J.stp, EVP-AWBD4A.step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]
2026-07-20 Add files via upload
    Added PCB manufacturing, BOM, and kicad files
    [STM32H755_DevBoard-B_Mask.gbr, STM32H755_DevBoard-B_Paste.gbr, STM32H755_DevBoard-Bottom.gbr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]
2026-07-20 Rename Screenshot 2026-07-20 131803.png to Images/PCB_Top.png
2026-07-23 Add section headers for footprint pictures
2026-08-07 Update PCB quantity in the parts list
